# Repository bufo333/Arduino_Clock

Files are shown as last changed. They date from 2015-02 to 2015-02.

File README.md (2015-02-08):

 # Arduino_Clock 

 This code will allow you to power an arduino atmega328 based mcu. The clock uses three four character seven segment displays connected via I2C protocol via an Adafruit Led backpack product id's(878, 880, 879). The clock stores and reads time via i2c using a ds1307 RTC which is connected via I2C as well. The clock uses the ADC analogue pins to read temperature from a tmp36 sensor. Additionally a Honeywell hih 4001 relative humidity sensor is also included in the project. The code will automatically use the temperature to generate a temperature corrected RH reading. 

 The code includes 21 ringtones which are stored in RTTL (Ringtone Transfer Language), the code to decode the ringtones was written by Brett Hagman. I have modified the code to store the ringtones in progmem thus saving memory. The code also includes an alarm, with an on off switch that is coded to a single throw double pole switch. This switch is a master arm for the alarm.

 The clock has 3 buttons and 3 display modes and 5 set modes. The buttons are brightness, 12/24 hour toggle, and display mode. The brightness has 4 levels of brightness.  The display modes are:

 	1. Calendar mode - This mode shows the time, month , date, and year.
 	2. Environment mode - This mode shows the time, temperature and humidity
 	3. Alarm mode - This mode shows the time, month and day, and the alarm set time.

 The clock also has 5 set modes. Note that during the set mode the three buttons have different functions. You enter the set mode by holding down the mode button for 3 seconds. You know you are in set mode because the decimals underneath each digit of a 4 character display will flash on and off two times a second. As in display mode pressing the mode button will change the set mode. Holding the set mode button down for 3 additional seconds will exit set mode. The set modes are as follows:

 1. Set the hours and minutes - In this mode the brightness button becomes the minute adjust press once or hold for faster setting. The 24 hour time select button is used to set the hours.

 2. Month/Day set - In this mode the brightness and the 24/hour mode buttons are pressed to set the day and month respectively. Again holding down the button will scroll through the values at a faster rate.

 3. Year set mode - In this mode the brightness increments the years by 1 and the 24/hour mode button increments the year by 10. Again  holding either of the buttons down will increase the scroll rate.

 4. Alarm set mode - In this mode the alarm can be set. Note the alarm is always displayed in 24/hour time mode to prevent confusion. Again as with time the brightness button will set the minutes and the 24/hour mode button will set the hours.

 5. Alarm ring tone  - This mode will allow you to choose from the 21 ringtones that are available to you and it will play  the first 5 seconds of each ringtone as a preview.

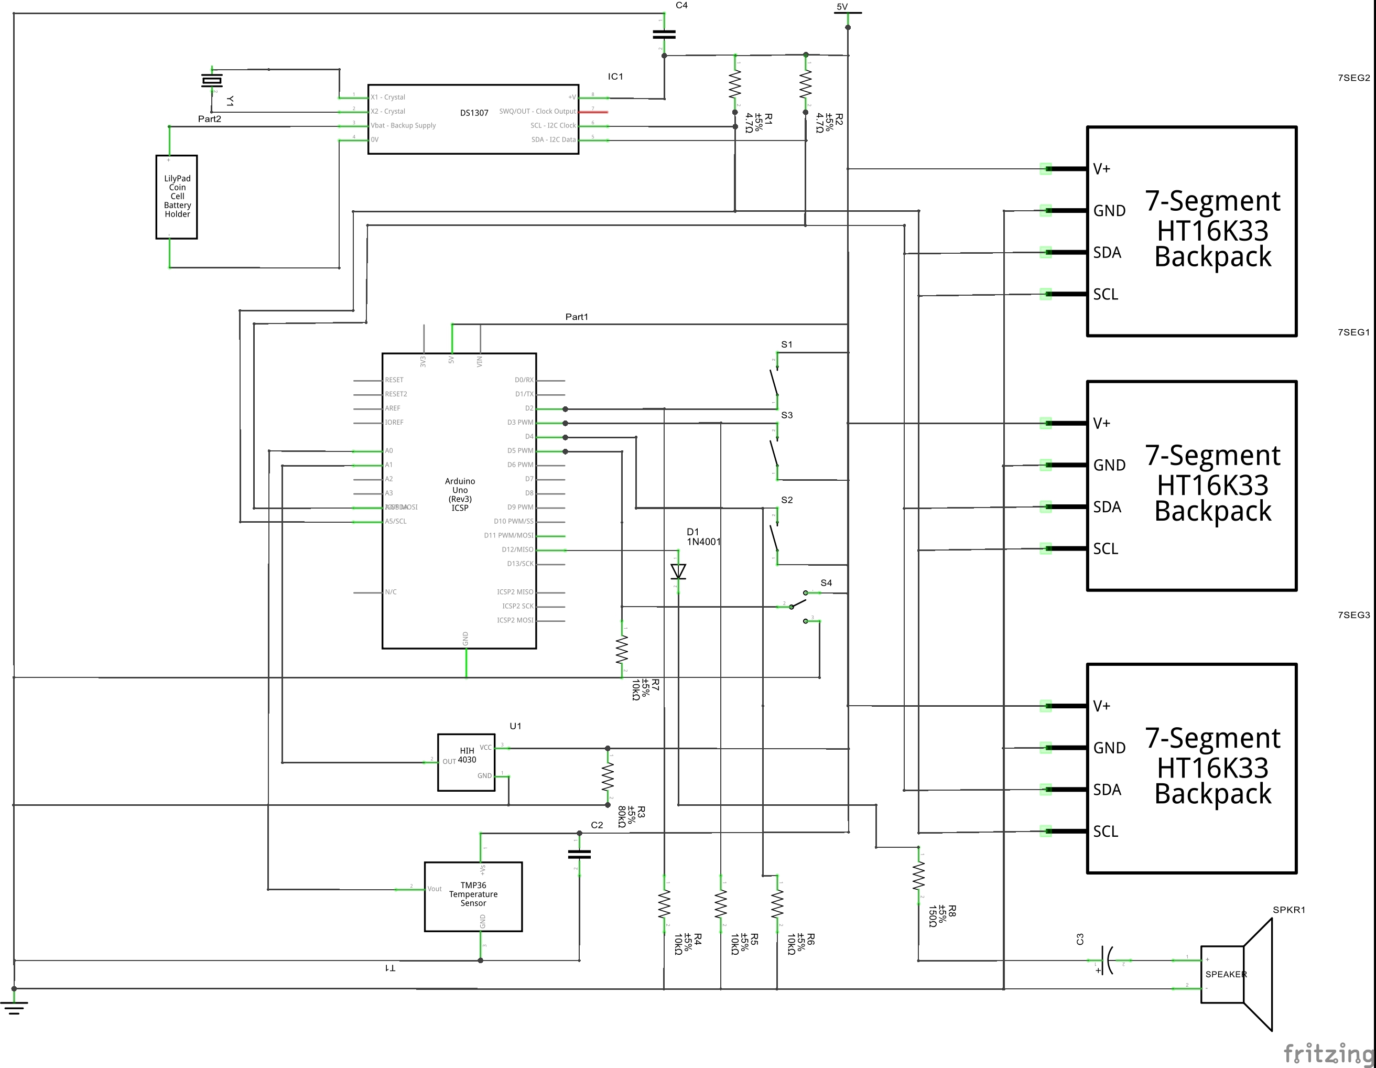
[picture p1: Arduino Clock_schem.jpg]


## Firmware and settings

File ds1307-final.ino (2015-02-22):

/*
* 7 Segment Alarm Clock With temp and Humidity Sensors
*
* The code includes the clock functionality for communicating with a ds1307,
* Communicating with the adafruit 7 segment led backpacks, and reading the
* temperature and humidity settings. The program uses the millis() feature
* to perform timed tasks without halting execution. The program will display
* the time in 12 hour and 24 hour modes, display temperature and humidity,
* as well as show the full calendar year. The code to decode the ringtones was 
* written by Brett Hagman.
*
* written by John Burns
*
*
*/

//Include the needed Libraries

#include <Wire.h>
#include "RTClib.h"
#include "Adafruit_LEDBackpack.h"
#include "Adafruit_GFX.h"
#include <avr/pgmspace.h>
#include <EEPROM.h>
#define isdigit(n) (n >= '0' && n <= '9')
#define OCTAVE_OFFSET 0
// Declare variables and instantiate objects
Adafruit_7segment matrix = Adafruit_7segment();
Adafruit_7segment matrix1 = Adafruit_7segment();
Adafruit_7segment matrix2 = Adafruit_7segment();
RTC_DS1307 rtc;

// Create constants
const byte hourPin = 4;
const byte minPin = 2;
const byte modePin = 3;
const byte tonePin = 13;
const bool alarmPin = 6;
const byte tempSensor = A1;
const byte humidSensor = A0;
const int notes[] = { 0,
262, 277, 294, 311, 330, 349, 370, 392, 415, 440, 466, 494,
523, 554, 587, 622, 659, 698, 740, 784, 831, 880, 932, 988,
1047, 1109, 1175, 1245, 1319, 1397, 1480, 1568, 1661, 1760, 1865, 1976,
2093, 2217, 2349, 2489, 2637, 2794, 2960, 3136, 3322, 3520, 3729, 3951
};
const char song_20[] PROGMEM = "The Simpsons:d=4,o=5,b=160:c.6,e6,f#6,8a6,g.6,e6,c6,8a,8f#,8f#,8f#,2g,8p,8p,8f#,8f#,8f#,8g,a#.,8c6,8c6,8c6,c6";
const char song_19[] PROGMEM = "Indiana:d=4,o=5,b=250:e,8p,8f,8g,8p,1c6,8p.,d,8p,8e,1f,p.,g,8p,8a,8b,8p,1f6,p,a,8p,8b,2c6,2d6,2e6,e,8p,8f,8g,8p,1c6,p,d6,8p,8e6,1f.6,g,8p,8g,e.6,8p,d6,8p,8g,e.6,8p,d6,8p,8g,f.6,8p,e6,8p,8d6,2c6";
const char song_18[] PROGMEM = "TakeOnMe:d=4,o=4,b=160:8f#5,8f#5,8f#5,8d5,8p,8b,8p,8e5,8p,8e5,8p,8e5,8g#5,8g#5,8a5,8b5,8a5,8a5,8a5,8e5,8p,8d5,8p,8f#5,8p,8f#5,8p,8f#5,8e5,8e5,8f#5,8e5,8f#5,8f#5,8f#5,8d5,8p,8b,8p,8e5,8p,8e5,8p,8e5,8g#5,8g#5,8a5,8b5,8a5,8a5,8a5,8e5,8p,8d5,8p,8f#5,8p,8f#5,8p,8f#5,8e5,8e5";
const char song_17[] PROGMEM = "Entertainer:d=4,o=5,b=140:8d,8d#,8e,c6,8e,c6,8e,2c.6,8c6,8d6,8d#6,8e6,8c6,8d6,e6,8b,d6,2c6,p,8d,8d#,8e,c6,8e,c6,8e,2c.6,8p,8a,8g,8f#,8a,8c6,e6,8d6,8c6,8a,2d6";
const char song_16[] PROGMEM = "Muppets:d=4,o=5,b=250:c6,c6,a,b,8a,b,g,p,c6,c6,a,8b,8a,8p,g.,p,e,e,g,f,8e,f,8c6,8c,8d,e,8e,8e,8p,8e,g,2p,c6,c6,a,b,8a,b,g,p,c6,c6,a,8b,a,g.,p,e,e,g,f,8e,f,8c6,8c,8d,e,8e,d,8d,c";
const char song_15[] PROGMEM = "Xfiles:d=4,o=5,b=125:e,b,a,b,d6,2b.,1p,e,b,a,b,e6,2b.,1p,g6,f#6,e6,d6,e6,2b.,1p,g6,f#6,e6,d6,f#6,2b.,1p,e,b,a,b,d6,2b.,1p,e,b,a,b,e6,2b.,1p,e6,2b.";
const char song_14[] PROGMEM = "Looney:d=4,o=5,b=140:32p,c6,8f6,8e6,8d6,8c6,a.,8c6,8f6,8e6,8d6,8d#6,e.6,8e6,8e6,8c6,8d6,8c6,8e6,8c6,8d6,8a,8c6,8g,8a#,8a,8f";
const char song_13[] PROGMEM = "20thCenFox:d=16,o=5,b=140:b,8p,b,b,2b,p,c6,32p,b,32p,c6,32p,b,32p,c6,32p,b,8p,b,b,b,32p,b,32p,b,32p,b,32p,b,32p,b,32p,b,32p,g#,32p,a,32p,b,8p,b,b,2b,4p,8e,8g#,8b,1c#6,8f#,8a,8c#6,1e6,8a,8c#6,8e6,1e6,8b,8g#,8a,2b";
const char song_12[] PROGMEM = "Bond:d=4,o=5,b=80:32p,16c#6,32d#6,32d#6,16d#6,8d#6,16c#6,16c#6,16c#6,16c#6,32e6,32e6,16e6,8e6,16d#6,16d#6,16d#6,16c#6,32d#6,32d#6,16d#6,8d#6,16c#6,16c#6,16c#6,16c#6,32e6,32e6,16e6,8e6,16d#6,16d6,16c#6,16c#7,c.7,16g#6,16f#6,g#.6";
const char song_11[] PROGMEM = "MASH:d=8,o=5,b=140:4a,4g,f#,g,p,f#,p,g,p,f#,p,2e.,p,f#,e,4f#,e,f#,p,e,p,4d.,p,f#,4e,d,e,p,d,p,e,p,d,p,2c#.,p,d,c#,4d,c#,d,p,e,p,4f#,p,a,p,4b,a,b,p,a,p,b,p,2a.,4p,a,b,a,4b,a,b,p,2a.,a,4f#,a,b,p,d6,p,4e.6,d6,b,p,a,p,2b";
const char song_10[] PROGMEM = "StarWars:d=4,o=5,b=45:32p,32f#,32f#,32f#,8b.,8f#.6,32e6,32d#6,32c#6,8b.6,16f#.6,32e6,32d#6,32c#6,8b.6,16f#.6,32e6,32d#6,32e6,8c#.6,32f#,32f#,32f#,8b.,8f#.6,32e6,32d#6,32c#6,8b.6,16f#.6,32e6,32d#6,32c#6,8b.6,16f#.6,32e6,32d#6,32e6,8c#6";
const char song_9[] PROGMEM = "GoodBad:d=4,o=5,b=56:32p,32a#,32d#6,32a#,32d#6,8a#.,16f#.,16g#.,d#,32a#,32d#6,32a#,32d#6,8a#.,16f#.,16g#.,c#6,32a#,32d#6,32a#,32d#6,8a#.,16f#.,32f.,32d#.,c#,32a#,32d#6,32a#,32d#6,8a#.,16g#.,d#";
const char song_8[] PROGMEM = "TopGun:d=4,o=4,b=31:32p,16c#,16g#,16g#,32f#,32f,32f#,32f,16d#,16d#,32c#,32d#,16f,32d#,32f,16f#,32f,32c#,16f,d#,16c#,16g#,16g#,32f#,32f,32f#,32f,16d#,16d#,32c#,32d#,16f,32d#,32f,16f#,32f,32c#,g#";
const char song_7[] PROGMEM = "A-Team:d=8,o=5,b=125:4d#6,a#,2d#6,16p,g#,4a#,4d#.,p,16g,16a#,d#6,a#,f6,2d#6,16p,c#.6,16c6,16a#,g#.,2a#";
const char song_6[] PROGMEM = "Flinstones:d=4,o=5,b=40:32p,16f6,16a#,16a#6,32g6,16f6,16a#.,16f6,32d#6,32d6,32d6,32d#6,32f6,16a#,16c6,d6,16f6,16a#.,16a#6,32g6,16f6,16a#.,32f6,32f6,32d#6,32d6,32d6,32d#6,32f6,16a#,16c6,a#,16a6,16d.6,16a#6,32a6,32a6,32g6,32f#6,32a6,8g6,16g6,16c.6,32a6,32a6,32g6,32g6,32f6,32e6,32g6,8f6,16f6,16a#.,16a#6,32g6,16f6,16a#.,16f6,32d#6,32d6,32d6,32d#6,32f6,16a#,16c.6,32d6,32d#6,32f6,16a#,16c.6,32d6,32d#6,32f6,16a#6,16c7,8a#.6";
const char song_5[] PROGMEM = "Jeopardy:d=4,o=6,b=125:c,f,c,f5,c,f,2c,c,f,c,f,a.,8g,8f,8e,8d,8c#,c,f,c,f5,c,f,2c,f.,8d,c,a#5,a5,g5,f5,p,d#,g#,d#,g#5,d#,g#,2d#,d#,g#,d#,g#,c.7,8a#,8g#,8g,8f,8e,d#,g#,d#,g#5,d#,g#,2d#,g#.,8f,d#,c#,c,p,a#5,p,g#.5,d#,g#";
const char song_4[] PROGMEM = "Gadget:d=16,o=5,b=50:32d#,32f,32f#,32g#,a#,f#,a,f,g#,f#,32d#,32f,32f#,32g#,a#,d#6,4d6,32d#,32f,32f#,32g#,a#,f#,a,f,g#,f#,8d#";
const char song_3[] PROGMEM = "Smurfs:d=32,o=5,b=200:4c#6,16p,4f#6,p,16c#6,p,8d#6,p,8b,p,4g#,16p,4c#6,p,16a#,p,8f#,p,8a#,p,4g#,4p,g#,p,a#,p,b,p,c6,p,4c#6,16p,4f#6,p,16c#6,p,8d#6,p,8b,p,4g#,16p,4c#6,p,16a#,p,8b,p,8f,p,4f#";
const char song_2[] PROGMEM = "MahnaMahna:d=16,o=6,b=125:c#,c.,b5,8a#.5,8f.,4g#,a#,g.,4d#,8p,c#,c.,b5,8a#.5,8f.,g#.,8a#.,4g,8p,c#,c.,b5,8a#.5,8f.,4g#,f,g.,8d#.,f,g.,8d#.,f,8g,8d#.,f,8g,d#,8c,a#5,8d#.,8d#.,4d#,8d#.";
const char song_1[] PROGMEM = "LeisureSuit:d=16,o=6,b=56:f.5,f#.5,g.5,g#5,32a#5,f5,g#.5,a#.5,32f5,g#5,32a#5,g#5,8c#.,a#5,32c#,a5,a#.5,c#.,32a5,a#5,32c#,d#,8e,c#.,f.,f.,f.,f.,f,32e,d#,8d,a#.5,e,32f,e,32f,c#,d#.,c#";
const char song_0[] PROGMEM = "MissionImp:d=16,o=6,b=95:32d,32d#,32d,32d#,32d,32d#,32d,32d#,32d,32d,32d#,32e,32f,32f#,32g,g,8p,g,8p,a#,p,c7,p,g,8p,g,8p,f,p,f#,p,g,8p,g,8p,a#,p,c7,p,g,8p,g,8p,f,p,f#,p,a#,g,2d,32p,a#,g,2c#,32p,a#,g,2c,a#5,8c,2p,32p,a#5,g5,2f#,32p,a#5,g5,2f,32p,a#5,g5,2e,d#,8d";
const char *song_table[] ={"0",
  song_0,
  song_1,
  song_2,
  song_3,
  song_4,
  song_5,
  song_6,
  song_7,
  song_8,
  song_9,
  song_10,
  song_11,
  song_12,
  song_13,
  song_14,
  song_15,
  song_16,
  song_17,
  song_18,
  song_10,
  song_20 };
 
// Create variables
DateTime alarm;
DateTime now;
float tempC;
float tempF;
bool AMPM;
bool alarmSet;
byte brightness;
byte mode;
byte smode;
byte alarmTone;
float trueRH;
bool setMode;
char buf[421];
byte choice =1;
unsigned long smodeTimer;
unsigned long modePinTimer;
unsigned long buttonTimer;
unsigned long minPinTimer;
unsigned long hourPinTimer;
unsigned long sensorTimer;
unsigned long displayTicks;
unsigned long rtcTicks;

// Setup function only done once.
void setup () {

  // Set pin registers
  pinMode(tempSensor, INPUT);
  pinMode(humidSensor, INPUT);
  pinMode(hourPin, INPUT);
  pinMode(minPin, INPUT);
  pinMode(modePin, INPUT);
  pinMode(tonePin, INPUT);
  // Assign default variable values.
  brightness = 15;
  alarmTone=8;
  strcpy_P(buf, (char*)(song_table[alarmTone]));
  setMode = false;
  smode = 0;
  AMPM = false;
  // Start the various communication buses and set starting values
  matrix.begin(0x71);
  matrix.setBrightness(brightness);
  matrix1.begin(0x70);
  matrix1.setBrightness(brightness);
  matrix2.begin(0x72);
  matrix2.setBrightness(brightness);
  // Conditional compile statements
#ifdef AVR
  Wire.begin();
#else
  Wire1.begin(); // Shield I2C pins connect to alt I2C bus on Arduino Due
#endif
  rtc.begin();
  // If RTC looses power start the clock and issue a default starting time.
  if (! rtc.isrunning()) {
    rtc.adjust(DateTime(1983, 11, 07, 0, 0, 0));
  }
}

// Main program loop
void loop () {

  // Detect if the Set Mode has been enabled if its not check the pin status.
  if (!setMode) {
    ReadPins();
    CheckAlarm();
  }
  else {
    ReadPinsSet();
  }
  // Update displays
  DisplayAll();
  // Poll the sensors ever second
  if (millis() - sensorTimer >= 1000UL) {
    GetTemp();
    GetHumid();
    sensorTimer = millis();
  }

}

//Main display function. This function updates the LED's based on mode and settings menu.
void DisplayAll() {
  // Local variables
  static bool m0select;
  static bool m1select;
  static bool m2select;
  static byte colon;
  now = rtc.now();
  byte minutes = now.minute();
  byte hours = now.hour();
  int years = now.year();
  byte months = now.month();
  byte days = now.day();
  byte aminutes = alarm.minute();
  byte ahours = alarm.hour();

  // Sets the period for the LED periods to blink twice a second
  if ( millis() - smodeTimer >= 500UL) {
    if (setMode) {
      if (smode == 0) {
        m2select = !m2select;
        m1select = false;
        m0select = false;
      }
      else if (smode == 1) {
        m1select = !m1select;
        m2select = false;
        m0select = false;
      }
      else if (smode == 2 || 3 || 4) {
        m0select = !m0select;
        m2select = false;
        m1select = false;
      }
    }
    else {
      m0select = false;
      m1select = false;
      m2select = false;
    }
    smodeTimer = millis();
  }
  
  // Draw colon ever second on time display
  if (millis() - rtcTicks >= 1000) {
    if (colon == 0) {
      colon = 1;
      matrix2.drawColon(colon);

    }
    else {
      colon = 0;
      matrix2.drawColon(colon);

    }
    matrix2.writeDisplay();

    rtcTicks = millis();
  }
  
  
  // Make sure any changes to the brightness variable is adjusted
  // no later than every 100ms. And apply blink profiles for set modes
  if (millis() - displayTicks >= 100UL) {
    matrix.setBrightness(brightness);
    matrix1.setBrightness(brightness);
    matrix2.setBrightness(brightness);

    if ( (!setMode && mode == 0) || (setMode && smode <3)) {
      matrix.writeDigitNum(0, (years / 1000) , m0select);
      matrix.writeDigitNum(1, (years / 100) % 10 , m0select);
      matrix.writeDigitNum(3, (years / 10) % 10, m0select);
      matrix.writeDigitNum(4, (years % 10), m0select);
      matrix.drawColon(false);
      matrix.writeDisplay();
    }
    else if ( (!setMode && mode == 2) || (setMode && smode == 3)) {
      matrix.writeDigitNum(0, (ahours / 10) , m0select);
      matrix.writeDigitNum(1, (ahours % 10) , m0select);
      matrix.writeDigitNum(3, (aminutes / 10), m0select);
      matrix.writeDigitNum(4, (aminutes % 10), m0select);
      matrix.drawColon(true);
      matrix.writeDisplay();
    }
    else if ( (!setMode && mode == 1)) {
      int rh = trueRH * 100;
      matrix.writeDigitNum(0, rh / 1000 , m0select);
      matrix.writeDigitNum(1, (rh / 100) % 10 , true);
      matrix.writeDigitNum(3, (rh / 10) % 10, m0select);
      matrix.writeDigitNum(4, rh % 10, m0select);
      matrix.drawColon(false);
      matrix.writeDisplay();
    }
    else if ((setMode && smode == 4)) {
      matrix.writeDigitNum(0, (alarmTone / 1000) , m0select);
      matrix.writeDigitNum(1, (alarmTone/100) %10 , m0select);
      matrix.writeDigitNum(3, (alarmTone/10) %10,m0select);
      matrix.writeDigitNum(4, alarmTone %10, m0select);
      matrix.drawColon(false);
      matrix.writeDisplay();
      
    }
      
    if (!setMode && mode == 1) {
      int temp = tempF * 100.00;
      matrix1.writeDigitNum(0, temp / 1000 , m1select);
      matrix1.writeDigitNum(1, (temp / 100) % 10 , true);
      matrix1.writeDigitNum(3, (temp / 10) % 10, m1select);
      matrix1.writeDigitNum(4, temp % 10, m1select);
      matrix1.drawColon(false);
      matrix1.writeDisplay();
    }
    else {
      matrix1.writeDigitNum(0, months / 10 , m1select);
      matrix1.writeDigitNum(1, months % 10 , true);
      matrix1.writeDigitNum(3, days / 10, m1select);
      matrix1.writeDigitNum(4, days % 10, m1select);
      matrix1.drawColon(false);
      matrix1.writeDisplay();
    }
    if (AMPM && hours > 12) {
      hours = hours - 12;
    }
    matrix2.writeDigitNum(0, hours / 10 , m2select);
    matrix2.writeDigitNum(1, hours % 10 , m2select);
    matrix2.writeDigitNum(3, minutes / 10, m2select);
    matrix2.writeDigitNum(4, minutes % 10, m2select);
    matrix2.writeDisplay();

    displayTicks = millis();
  }
}


// Read input pins and set variables
void ReadPinsSet() {
  
  // Set local variables
  byte minPinState;
  static byte minPinLastState;
  byte hourPinState;
  static byte hourPinLastState;
  byte modePinState;
  static byte modePinLastState;

  if (millis() - buttonTimer >= 10UL) {
    minPinState = digitalRead(minPin);
    hourPinState = digitalRead(hourPin);
    modePinState = digitalRead(modePin);
    alarmSet = digitalRead(alarmPin);
  }

  if (millis() - buttonTimer >= 100UL) {

    if (minPinState == 0) {
      minPinLastState = 0;
    }
    if (hourPinState == 0) {
      hourPinLastState = 0;
    }
    if (modePinState == 0) {
      modePinLastState = 0;
    }

    if (minPinState == 1 && minPinLastState == 0) {
      minPinLastState = 1;
      minPinTimer = millis();
      if (smode == 0) {
        SetTime('m');
      }
      else if (smode == 1) {
        SetDate('d');
      }
      else if (smode == 2) {
        SetDate('y');
      }
      else if (smode == 3) {
        SetAlarm('m');
      }
      else if (smode ==4) {
        SetAlarmTone('m');
      }
    }
    if (minPinState == 1 && minPinLastState == 1) {
      if (millis() - minPinTimer >= 1000UL) {
        if (smode == 0) {
          SetTime('m');
        }
        else if (smode == 1) {
          SetDate('d');
        }
        else if (smode == 2) {
          SetDate('y');
        }
        else if (smode == 3) {
          SetAlarm('m');
        }
        else if (smode ==4) {
          SetAlarmTone('m');
      }
    }
    }

    if (hourPinState == 1 && hourPinLastState == 0 ) {
      hourPinLastState = 1;
      hourPinTimer = millis();
      if (smode == 0) {
        SetTime('h');
      }
      else if (smode == 1) {
        SetDate('m');
      }
      else if (smode == 2) {
        SetDate('z');
      }
      else if (smode == 3) {
        SetAlarm('h');
      }
      else if (smode ==4) {
        SetAlarmTone('h');
      }
    }
    if (hourPinState == 1 && hourPinLastState == 1) {
      if (millis() - hourPinTimer >= 1000UL) {
        if (smode == 0) {
          SetTime('h');
        }
        else if (smode == 1) {
          SetDate('m');
        }
        else if (smode == 2) {
          SetDate('z');
        }
        else if (smode == 3) {
          SetAlarm('h');
        }
      }
    }

    if (modePinState == 1 && modePinLastState == 0 ) {
      modePinLastState = 1;
      modePinTimer = millis();
      if (smode + 1 <= 4) {
        smode += 1;
      }
      else {
        smode = 0;
      }
    }
    if (modePinState == 1 && modePinLastState == 1) {
      if (millis() - modePinTimer >= 3000UL) {
        setMode = !setMode;
        smode=0;
        modePinTimer = millis();
       
     }

    }

    buttonTimer = millis();
  }
  
}

void ReadPins() {

  byte minPinState;
  static byte minPinLastState;
  byte hourPinState;
  static byte hourPinLastState;
  byte modePinState;
  static byte modePinLastState;

  if (millis() - buttonTimer >= 10UL) {
    minPinState = digitalRead(minPin);
    hourPinState = digitalRead(hourPin);
    modePinState = digitalRead(modePin);
    alarmSet = digitalRead(alarmPin);
  }

  if (millis() - buttonTimer >= 100UL) {

    if (minPinState == 0) {
      minPinLastState = 0;
    }
    if (hourPinState == 0) {
      hourPinLastState = 0;
    }
    if (modePinState == 0) {
      modePinLastState = 0;
    }

    if (minPinState == 1 && minPinLastState == 0) {
      minPinLastState = 1;
      minPinTimer = millis();
      if (brightness + 5 <= 15) {
        brightness += 5;
      }
      else {
        brightness = 0;
      }
    }
    if (minPinState == 1 && minPinLastState == 1) {
      if (millis() - minPinTimer >= 1000UL) {
        if (brightness + 5 <= 15) {
          brightness += 5;
        }
        else {
          brightness = 0;
        }
      }
    }

    if (hourPinState == 1 && hourPinLastState == 0 ) {
      hourPinLastState = 1;
      hourPinTimer = millis();
      AMPM = !AMPM;
    }

    if (modePinState == 1 && modePinLastState == 0 ) {
      modePinLastState = 1;
      modePinTimer = millis();
      if (mode + 1 <= 2) {
        mode += 1;
      }
      else {
        mode = 0;
      }
    }
    if (modePinState == 1 && modePinLastState == 1) {
      if (millis() - modePinTimer >= 3000UL) {
        setMode = !setMode;
        modePinTimer = millis();
      }
    }

    buttonTimer = millis();
  }

}

void SetDate(char opt) {
  now = rtc.now();

  if (opt == 'm') {
    if (now.month() + 1 <= 12) {
      rtc.adjust(DateTime(now.year(), now.month() + 1, now.day(), now.hour(), now.minute(), now.second() ));
    }
    else {
      rtc.adjust(DateTime(now.year(), 1, now.day(), now.hour(), now.minute() , now.second() ));
    }
    DisplayAll();
  }
  if (opt == 'd') {

    if (now.month() == 2) {
      if (now.day() + 1 <= 28) {

        rtc.adjust(DateTime(now.year(), now.month(), now.day() + 1, now.hour() , now.minute() , now.second() ));
      }
      else {
        rtc.adjust(DateTime(now.year(), now.month(), 1, now.hour(), now.minute(), now.second()));
      }
    }
    else if (now.month() == 9 || now.month() == 11) {
      if (now.day() + 1 <= 30) {

        rtc.adjust(DateTime(now.year(), now.month(), now.day() + 1, now.hour() , now.minute() , now.second() ));
      }
      else {
        rtc.adjust(DateTime(now.year(), now.month(), 1, now.hour(), now.minute(), now.second()));
      }
    }
    else if (now.day() + 1 <= 31) {

      rtc.adjust(DateTime(now.year(), now.month(), now.day() + 1, now.hour() , now.minute() , now.second() ));
    }
    else {
      rtc.adjust(DateTime(now.year(), now.month(), 1, now.hour(), now.minute() , now.second() ));
    }
    DisplayAll();
  }

  if (opt == 'y') {
    if (now.year() + 1 <= 2100) {
      rtc.adjust(DateTime(now.year() + 1, now.month(), now.day(), now.hour(), now.minute(), now.second() ));
    }
    else {
      rtc.adjust(DateTime(2015, now.month(), now.day(), now.hour(), now.minute() , now.second() ));
    }
    DisplayAll();
  }
  if (opt == 'z') {
    if (now.year() + 10 <= 2100) {
      rtc.adjust(DateTime(now.year() + 10, now.month(), now.day(), now.hour() , now.minute() , now.second() ));
    }
    else {
      rtc.adjust(DateTime(2015, now.month(), now.day(), now.hour(), now.minute() , now.second() ));
    }
    DisplayAll();
  }


}
void SetTime(char opt) {

  now = rtc.now();

  if (opt == 'm') {
    if (now.minute() + 1 <= 59) {
      rtc.adjust(DateTime(now.year(), now.month(), now.day(), now.hour(), now.minute() + 1, 0 ));
    }
    else {
      rtc.adjust(DateTime(now.year(), now.month(), now.day(), now.hour(), 0 , 0 ));
    }
    DisplayAll();
  }
  if (opt == 'h') {
    if (now.hour() + 1 <= 23) {
      rtc.adjust(DateTime(now.year(), now.month(), now.day(), now.hour() + 1, now.minute() , now.second() ));
    }
    else {
      rtc.adjust(DateTime(now.year(), now.month(), now.day(), 0, now.minute() , now.second() ));
    }
    DisplayAll();
  }
}
void SetAlarm(char opt) {


  if (opt == 'm') {
    if (alarm.minute() + 1 <= 59) {
      alarm = DateTime(alarm.year(), alarm.month(), alarm.day(), alarm.hour(), alarm.minute() + 1, 0 );
    }
    else {
      alarm = DateTime(alarm.year(), alarm.month(), alarm.day(), alarm.hour(), 0 , 0 );
    }
    DisplayAll();
  }
  if (opt == 'h') {
    if (alarm.hour() + 1 <= 23) {
      alarm = DateTime(alarm.year(), alarm.month(), alarm.day(), alarm.hour() + 1, alarm.minute() , 0 );
    }
    else {
      alarm = DateTime(alarm.year(), alarm.month(), alarm.day(), 0, alarm.minute() , 0 );
    }
    DisplayAll();
  }

}


void GetHumid() {
  static int hreading[100];
  static byte hindex = 0;
  static unsigned int htotal = 0;
  int haverage = 0;
  float hvoltage;
  static unsigned long humidTimer;
  float refVolt = readVcc();

  if (millis() - humidTimer >= 10) {
    htotal = htotal - hreading[hindex];
    analogRead(humidSensor);
    analogRead(humidSensor);
    hreading[hindex] = analogRead(humidSensor);
    htotal = htotal + hreading[hindex];
    hindex += 1;
    humidTimer = millis();
  }

  if (hindex == 100) {
    hindex = 0;
  }
  haverage = htotal / 100;
  hvoltage = haverage * refVolt;
  hvoltage /= 1023.0;
  trueRH = (((hvoltage / 5.0) - 0.16) / 0.0062) / 1.0546 - 0.00216 * tempC;

}

void GetTemp() {
  static unsigned long tempTimer;
  float voltage;
  static int treading[100];
  static byte tindex = 0;
  static unsigned int ttotal = 0;
  int taverage = 0;
  float refVolt = readVcc();

  if (millis() - tempTimer >= 10) {
    ttotal = ttotal - treading[tindex];
    analogRead(tempSensor);
    analogRead(tempSensor);
    treading[tindex] = analogRead(tempSensor);
    ttotal = ttotal + treading[tindex];
    tindex += 1;
    tempTimer = millis();
  }
  if (tindex == 100) {
    tindex = 0;
  }
  taverage = ttotal / 100;
  voltage = taverage * refVolt;
  voltage /= 1023.0;
  tempC = (voltage - 0.5) * 100;
  tempF = (tempC * 9.0 / 5.0) + 32;
}

// Checks if the alarm should go off and activates the alarm tone.

void SetAlarmTone(char opt) {
  // Local variable declaration

  if (opt =='h') {
   PlayAlarm(0);
  }
  else {
    if (alarmTone + 1 <=21) {
    alarmTone +=1;
    DisplayAll();
  }
  else {
    alarmTone = 1;
  }
}
}

void CheckAlarm() {
  
  if (alarmSet) {
    if (now.hour() == alarm.hour() && now.minute() == alarm.minute()) {
     PlayAlarm(0);   
    }
  }
}
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

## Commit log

2015-02-07 Added Circuit Drawing and Files
    [Arduino Clock.fzz]
2015-02-08 Fixed alarm clock issue with clock not firing.
    [Arduino Clock.fzz]
2015-02-22 Added VCC corrections to temp and humidity calculations.
    [ds1307-final.ino]
